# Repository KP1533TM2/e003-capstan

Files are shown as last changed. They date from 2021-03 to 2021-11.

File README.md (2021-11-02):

# e003-capstan
Проект блока управления ведущими двигателями ДМ-1, ДМ-5 (применяемые в магнитофонах Олимп, Электроника ТА1-003) с кварцевой стабилизацией.

Основан на коде [контроллера ведущего двигателя самодельной кассетной деки TK-140 leoniv](http://leoniv.diod.club/projects/audio/tk-140/tk-140.html).

ZCD для сетевого напряжения взят и адаптирован [отсюда](https://cdn.hackaday.io/files/1597066832861504/SimpleIsolatedZeroCrossDetector.pdf).

# Отличия от БУВД Олимп 005
- Иной форм-фактор платы (расчитано на доработанный Олимп 003);
- Силовой каскад реализован простым преобразователем напряжения в ток;
- ФАПЧ, формирование синусоидального тока выполнены на микроконтроллере;
- Реализовано торможение при смене скорости кратковременным реверсом;

# Схема
Актуальная версия схемы (для rev1) лежит [тут](/hw/rev1/main.pdf).

# TODO:
- [x] "чистовая" плата - предположительно rev1;
- [ ] АПЧ сетевого напряжения;
- [ ] переключение реле синхронно переходу через 0 для сбережения контактов (?);
- [ ] описание.

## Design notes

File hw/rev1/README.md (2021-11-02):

# Краткое описание rev1

Ревизия 1 - первая "чистовая" печатная плата.

[Схема этой платы](./main.pdf).

Основные моменты:
* Сложная оригинальная схема петлевого фильтра, модулятора тока и силового
каскада полностью заменена на фильтр ШИМ с преобразователем V→I с применением
полевого транзистора.
* Модуляция синусом реализована таблично и воздействует на выход PID-регулятора.
* Интервал полупериода сетевого напряжения снимается посредством схемы ZCD с
обмотки трансформатора, питающей ведущий двигатель.
* Номиналы схемы ZCD эмпирически подобраны так, чтобы при трехступенчатой форме
сетевого напряжения (с ИБП) схема стабильно формировала лог.0 при "ступеньке"
0В;
* Добавлены крепежные отверстия по периметру.

# Картинки

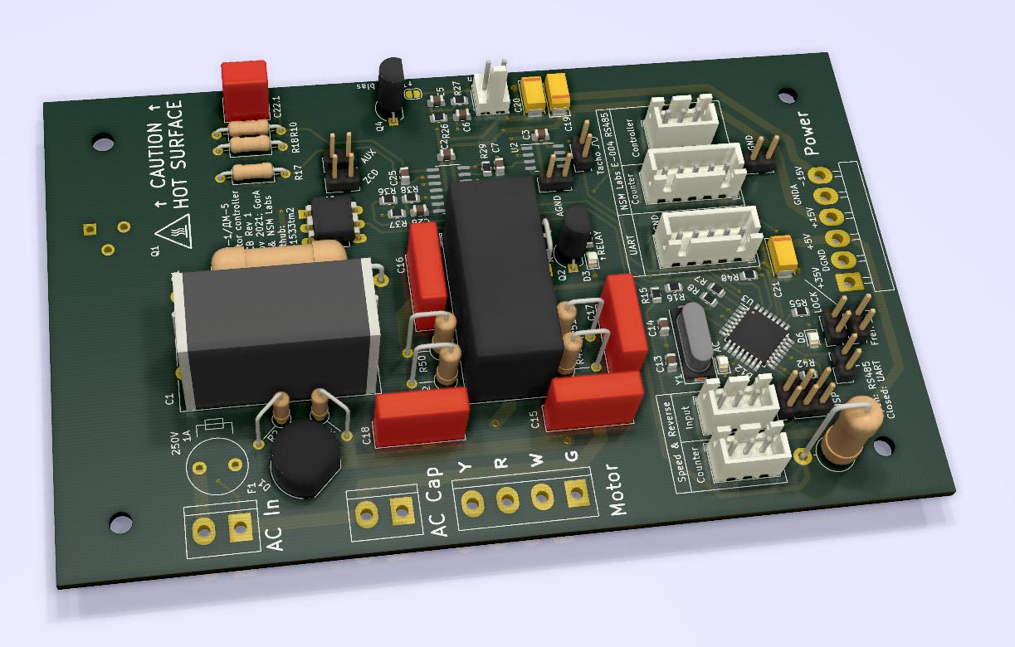
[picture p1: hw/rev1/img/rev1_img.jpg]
rev 1 pcb rev1


To be continued...

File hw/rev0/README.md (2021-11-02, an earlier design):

# Краткое описание rev0

Ревизия 0 - опытная печатная плата, на которой разведена схема аналогового
перемножителя на м/сх К504НТ3, обеспечивающего формирование синусоидального тока
двигателя.

[Схема этой платы](./main.pdf).

Схема ФАПЧ была заменена микроконтроллером.

Эта схема имеет ряд недостатков, основными из которых являются:
* Сложность в наладке;
* Трудонодоступность К504НТ3 и прочих полевых сборок;
* Схема обеспечивает модуляцию только при работе от переменного тока
синусоидальной формы.

# Картинки (макет rev1, rev0)

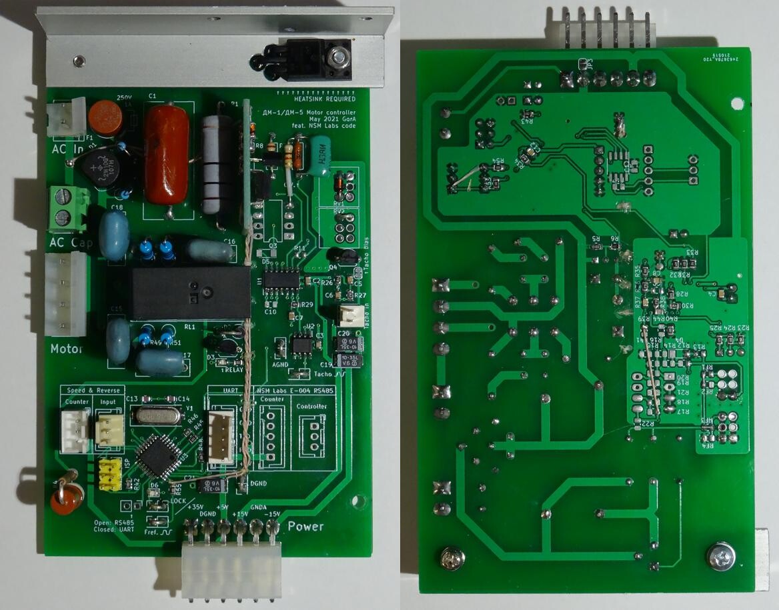
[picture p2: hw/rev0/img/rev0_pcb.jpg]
rev 0 top and bottom Макет rev1, собранный на плате rev0


Так выглядит плата rev0, с доработками, которые вошли в rev1.

Перпендикулярно распаянная макетная плата вблизи металлического уголка -
детектор перехода сетевого напряжения через 0 (Zero Crossing Detector),
необходимый для подстройки синтезируемого выпрямленного синуса к периоду
сетевого напряжения.

Вместо аналогового перемножителя распаян преобразователь напряжения в ток,
через который посредством фильтрованного PWM "напрямую", линейно управляет
микроконтроллер. Это позволяет осуществить модуляцию выхода PID-регулятора
модулем синуса программно, и тем самым избавиться от труднодоступной
транзисторной сборки К504НТ3 и её обвязки, нуждающейся в регулировке.

Дополнительный положительный побочный эффект такого решения заключается в
возможности работы этой схемы с переменным током формы, отличной от
синусоидальной (например, с трехступенчатой формой от ИБП).

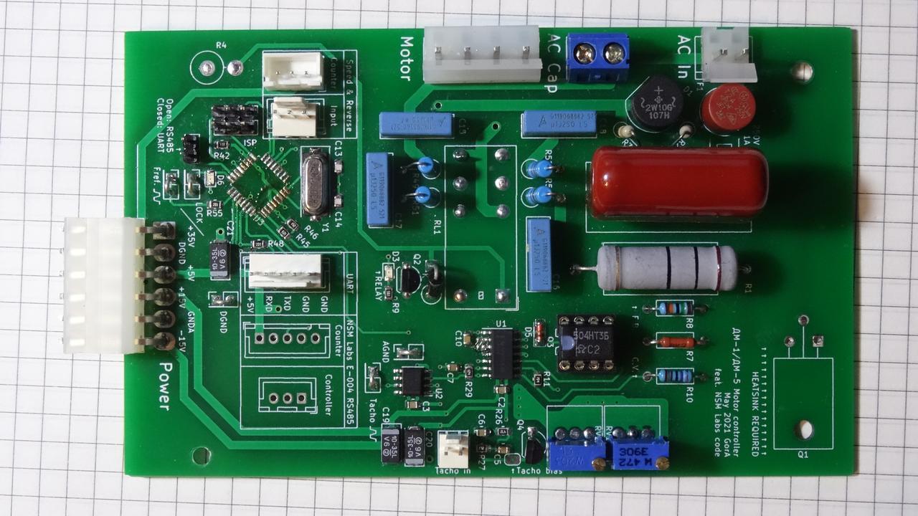
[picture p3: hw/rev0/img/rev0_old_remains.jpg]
rev 0 old Останки чистой, аналоговой rev0


Останки ревизии 0, собранные с аналоговым перемножителем-модулятором, для
истории.

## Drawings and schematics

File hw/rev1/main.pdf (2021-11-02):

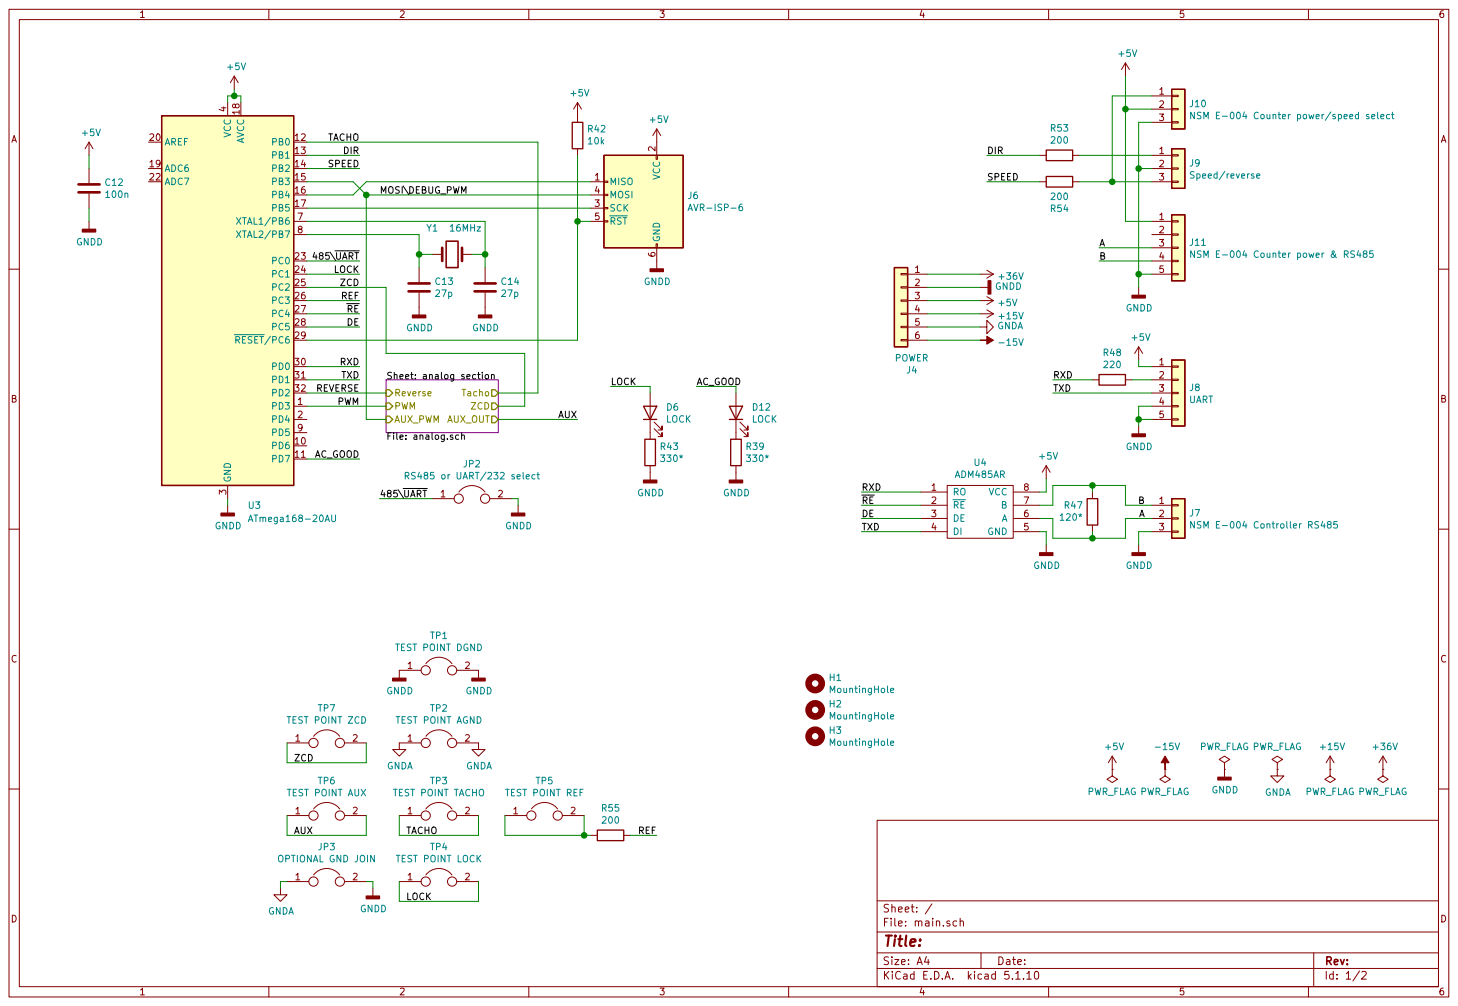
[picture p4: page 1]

2 SCK 3 MOSI 4 RST 5 GND

Sheet: analog section
File: analog.sch Tacho PWM

Id: 1/2 Title: File: main.sch Sheet: /

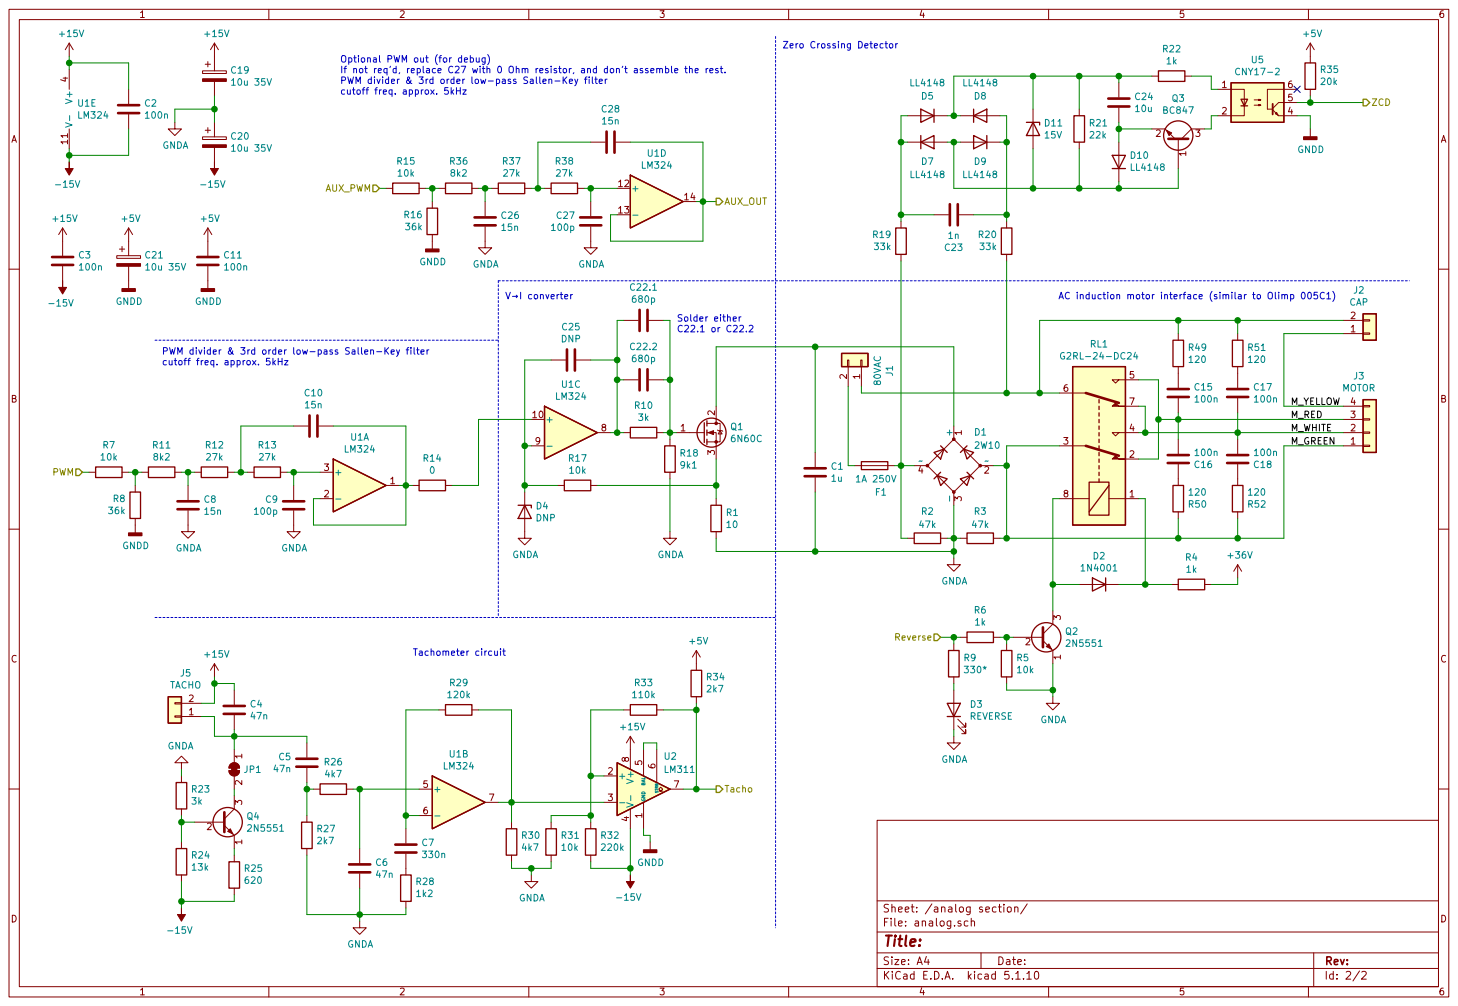
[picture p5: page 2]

Optional PWM out (for debug)
If not req'd, replace C27 with 0 Ohm resistor, and don't assemble the rest.
PWM divider & 3rd order low-pass Sallen-Key filter

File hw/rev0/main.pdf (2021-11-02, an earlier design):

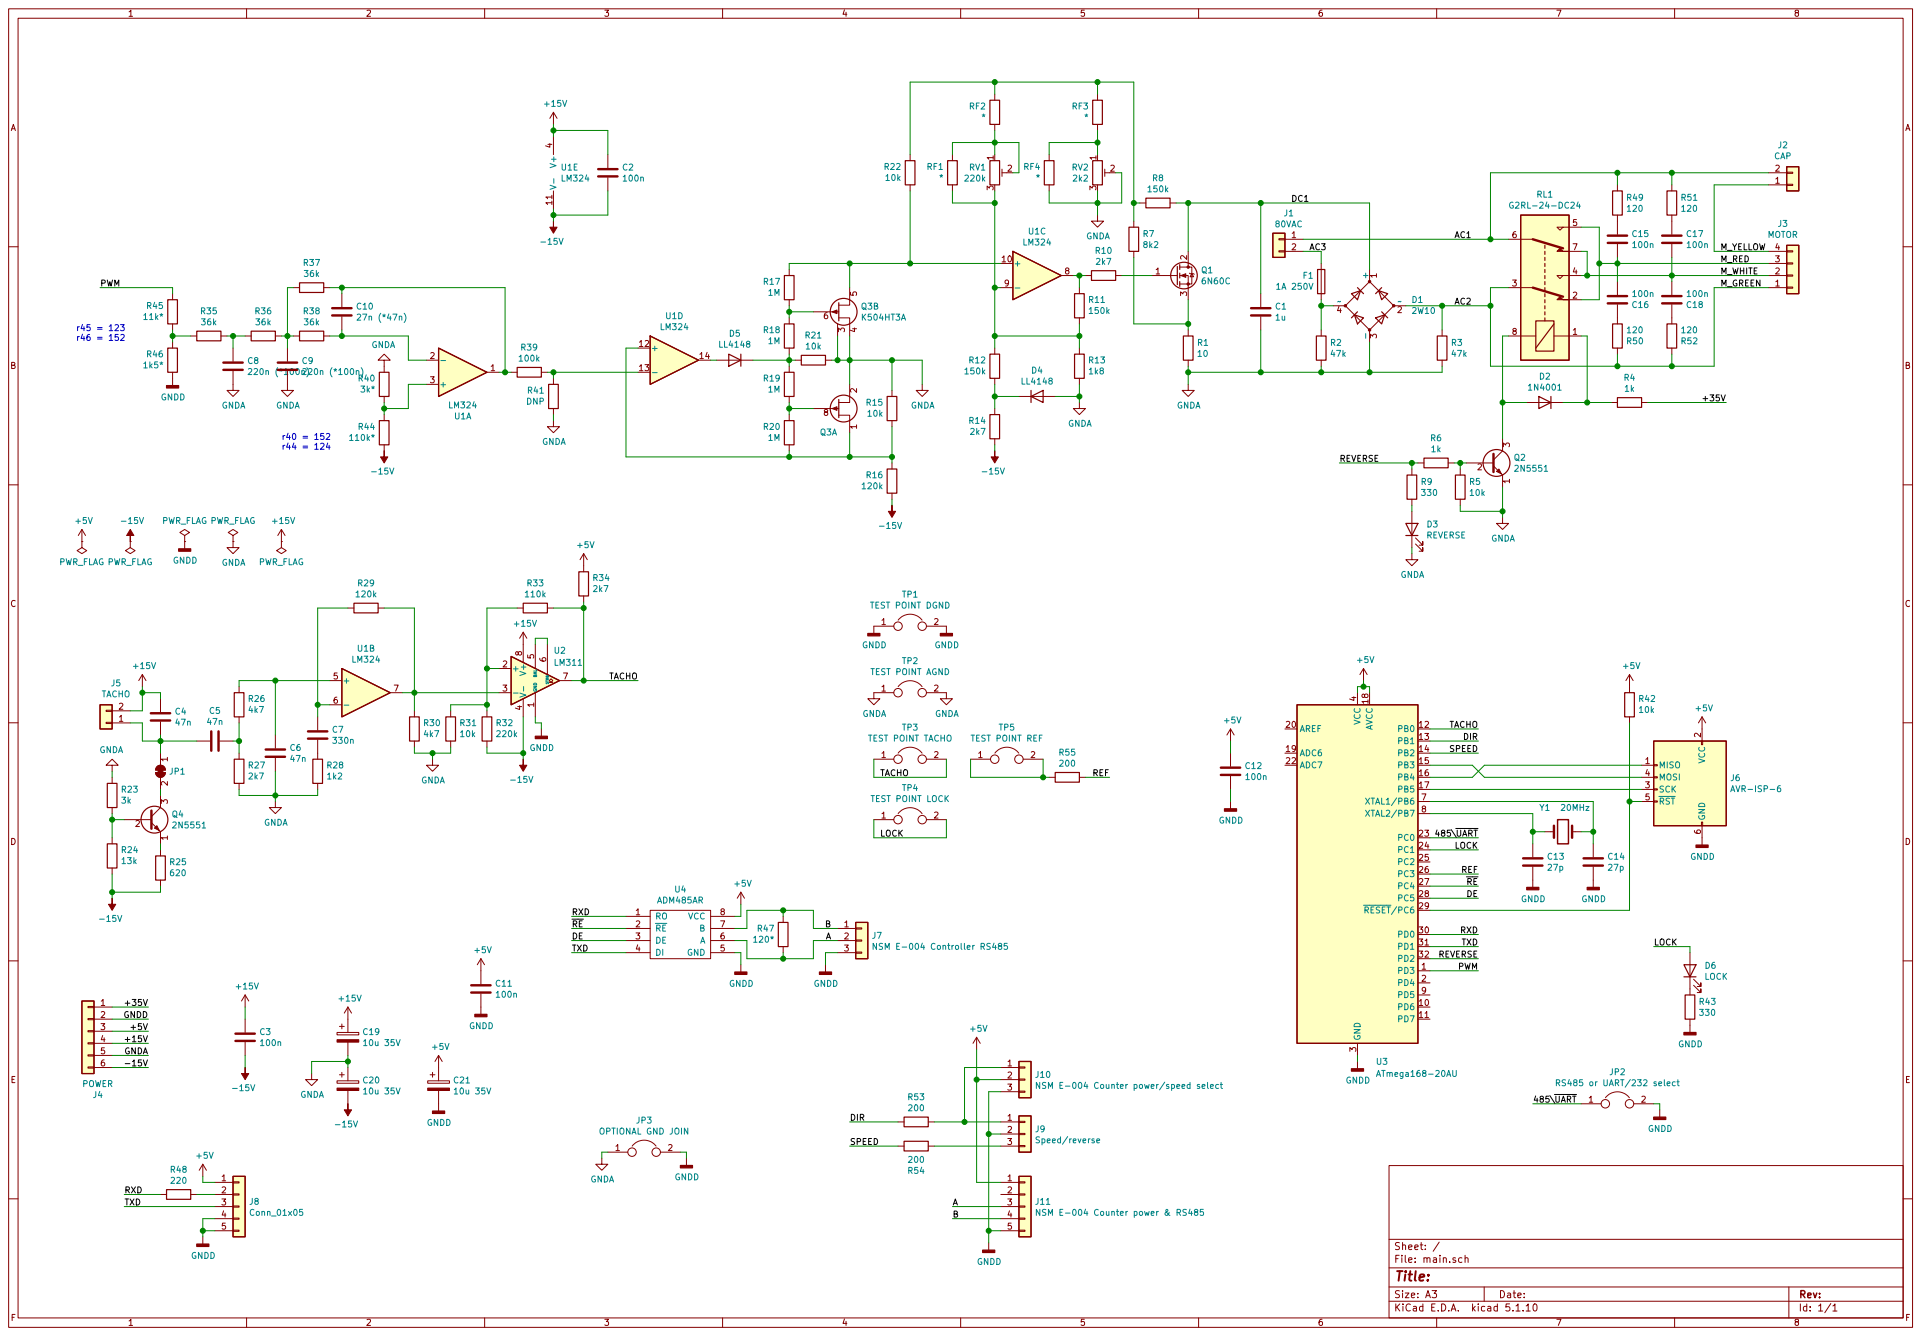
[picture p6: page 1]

J1 80VAC

Id: 1/1 Title: File: main.sch Sheet: /

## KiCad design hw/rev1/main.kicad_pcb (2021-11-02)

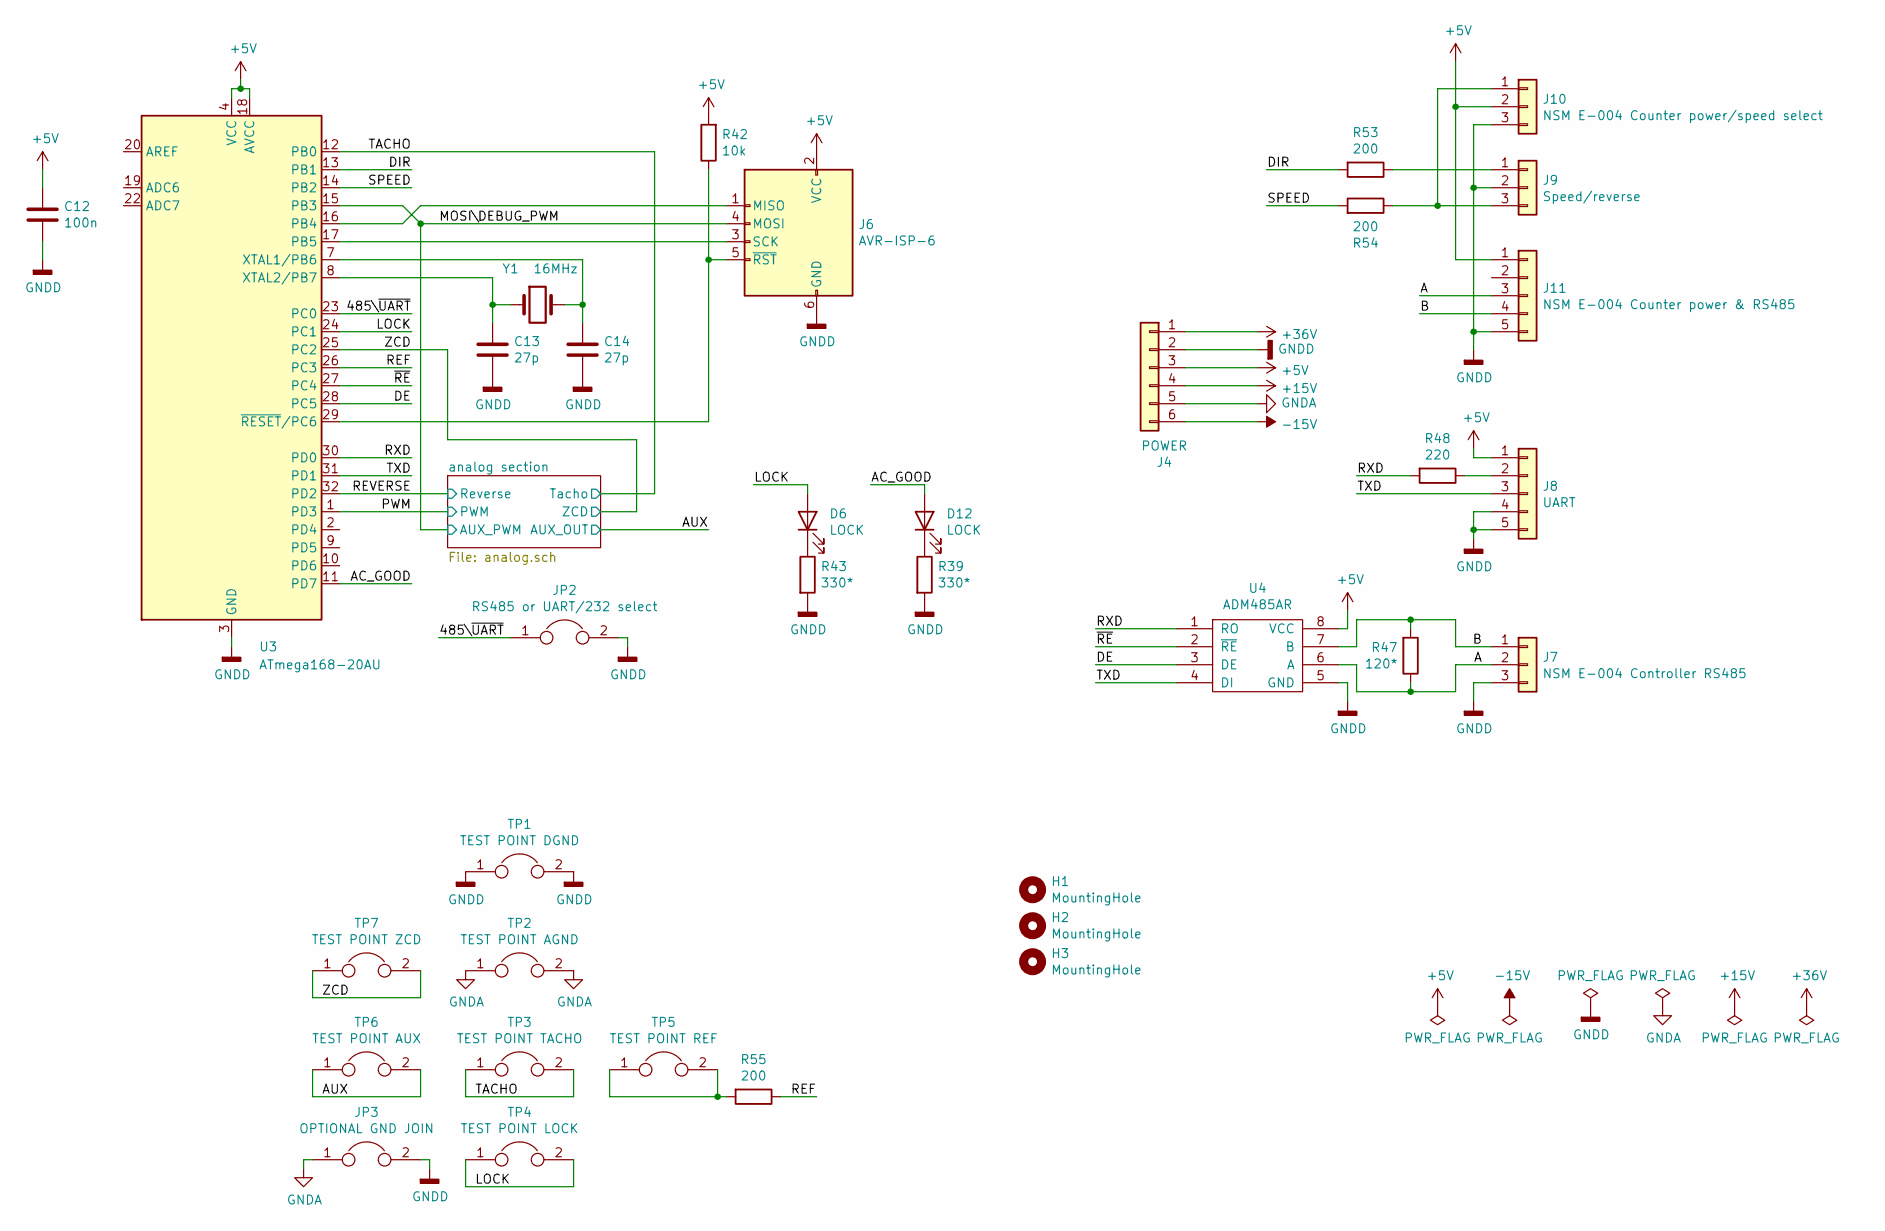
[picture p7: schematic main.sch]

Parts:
C12: 100n; C_0805_2012Metric
C13, C14: 27p; C_0805_2012Metric
D6, D12: LOCK; LED_0805_2012Metric
H1, H2, H3: MountingHole; MountingHole_3.2mm_M3
J4: POWER; Molex_KK-396_Right_Angle
J6: AVR-ISP-6; PinHeader_2x03_P2.54mm_Vertical
J7: NSM E-004 Controller RS485; JST_XH_B3B-XH-A_1x03_P2.50mm_Vertical
J8: UART; JST_XH_B5B-XH-A_1x05_P2.50mm_Vertical
J9: Speed/reverse; JST_XH_B3B-XH-A_1x03_P2.50mm_Vertical
J10: NSM E-004 Counter power/speed select; JST_XH_B3B-XH-A_1x03_P2.50mm_Vertical
J11: NSM E-004 Counter power & RS485; JST_XH_B5B-XH-A_1x05_P2.50mm_Vertical
JP2: RS485 or UART/232 select; PinHeader_1x02_P2.54mm_Vertical
JP3: OPTIONAL GND JOIN; SolderJumper-2_P1.3mm_Open_RoundedPad1.0x1.5mm
R39, R43: 330*; R_0805_2012Metric
R42: 10k; R_0805_2012Metric
R47: 120*; R_0805_2012Metric
R48: 220; R_0805_2012Metric
R53, R54, R55: 200; R_0805_2012Metric
TP1: TEST POINT DGND; PinHeader_2x01_P2.54mm_Vertical
TP2: TEST POINT AGND; PinHeader_2x01_P2.54mm_Vertical
TP3: TEST POINT TACHO; PinHeader_2x01_P2.54mm_Vertical
TP4: TEST POINT LOCK; PinHeader_2x01_P2.54mm_Vertical
TP5: TEST POINT REF; PinHeader_2x01_P2.54mm_Vertical
TP6: TEST POINT AUX; PinHeader_2x01_P2.54mm_Vertical
TP7: TEST POINT ZCD; PinHeader_2x01_P2.54mm_Vertical
U3: ATmega168-20AU; TQFP-32_7x7mm_P0.8mm
U4: ADM485AR; SO-8_3.9x4.9mm_P1.27mm
Y1: 16MHz; Crystal_SMD_HC49-SD

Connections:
+5V: C12.1, J4.3, J6.2 (VCC), J8.1, J10.2, J11.1, R42.2, U3.4 (VCC), U3.6 (VCC), U3.18 (AVCC), U4.8 (VCC); also elsewhere on the board
+15V: J4.4; also elsewhere on the board
+36V: J4.1; also elsewhere on the board
-15V: J4.6; also elsewhere on the board
/485\~UART: JP2.1, U3.23 (PC0)
/A: J7.2, J11.3, R47.1, U4.6 (A)
/AC_GOOD: D12.2 (A), U3.11 (PD7)
/AUX: TP6.1, TP6.2; also elsewhere on the board
/B: J7.1, J11.4, R47.2, U4.7 (B)
/DE: U3.28 (PC5), U4.3 (DE)
/DIR: R53.2, U3.13 (PB1)
/LOCK: D6.2 (A), TP4.1, TP4.2, U3.24 (PC1)
/MOSI\DEBUG_PWM: J6.4 (MOSI), U3.15 (PB3); also elsewhere on the board
/PWM: U3.1 (PD3); also elsewhere on the board
/REF: R55.1, U3.26 (PC3)
/REVERSE: U3.32 (PD2); also elsewhere on the board
/RXD: R48.2, U3.30 (PD0), U4.1 (RO)
/SPEED: R54.2, U3.14 (PB2)
/TACHO: TP3.1, TP3.2, U3.12 (PB0); also elsewhere on the board
/TXD: J8.3, U3.31 (PD1), U4.4 (DI)
/ZCD: TP7.1, TP7.2, U3.25 (PC2); also elsewhere on the board
/~RE: U3.27 (PC4), U4.2 (~RE)
GNDA: J4.5, JP3.1, TP2.1, TP2.2; also elsewhere on the board
GNDD: C12.2, C13.2, C14.2, J4.2, J6.6 (GND), J7.3, J8.4, J8.5, J9.2, J10.3, J11.5, JP2.2, JP3.2, R39.2, R43.2, TP1.1, TP1.2, U3.3 (GND), U3.5 (GND), U3.21 (GND), U4.5 (GND); also elsewhere on the board
unnamed: C13.1, U3.8 (XTAL2/PB7), Y1.1
unnamed: C14.1, U3.7 (XTAL1/PB6), Y1.2
unnamed: D6.1 (K), R43.1
unnamed: D12.1 (K), R39.1
unnamed: J6.1 (MISO), U3.16 (PB4)
unnamed: J6.3 (SCK), U3.17 (PB5)
unnamed: J6.5 (~RST), R42.1, U3.29 (~RESET~/PC6)
unnamed: J8.2, R48.1
unnamed: J9.1, R53.1
unnamed: J9.3, J10.1, R54.1
unnamed: R55.2, TP5.1, TP5.2

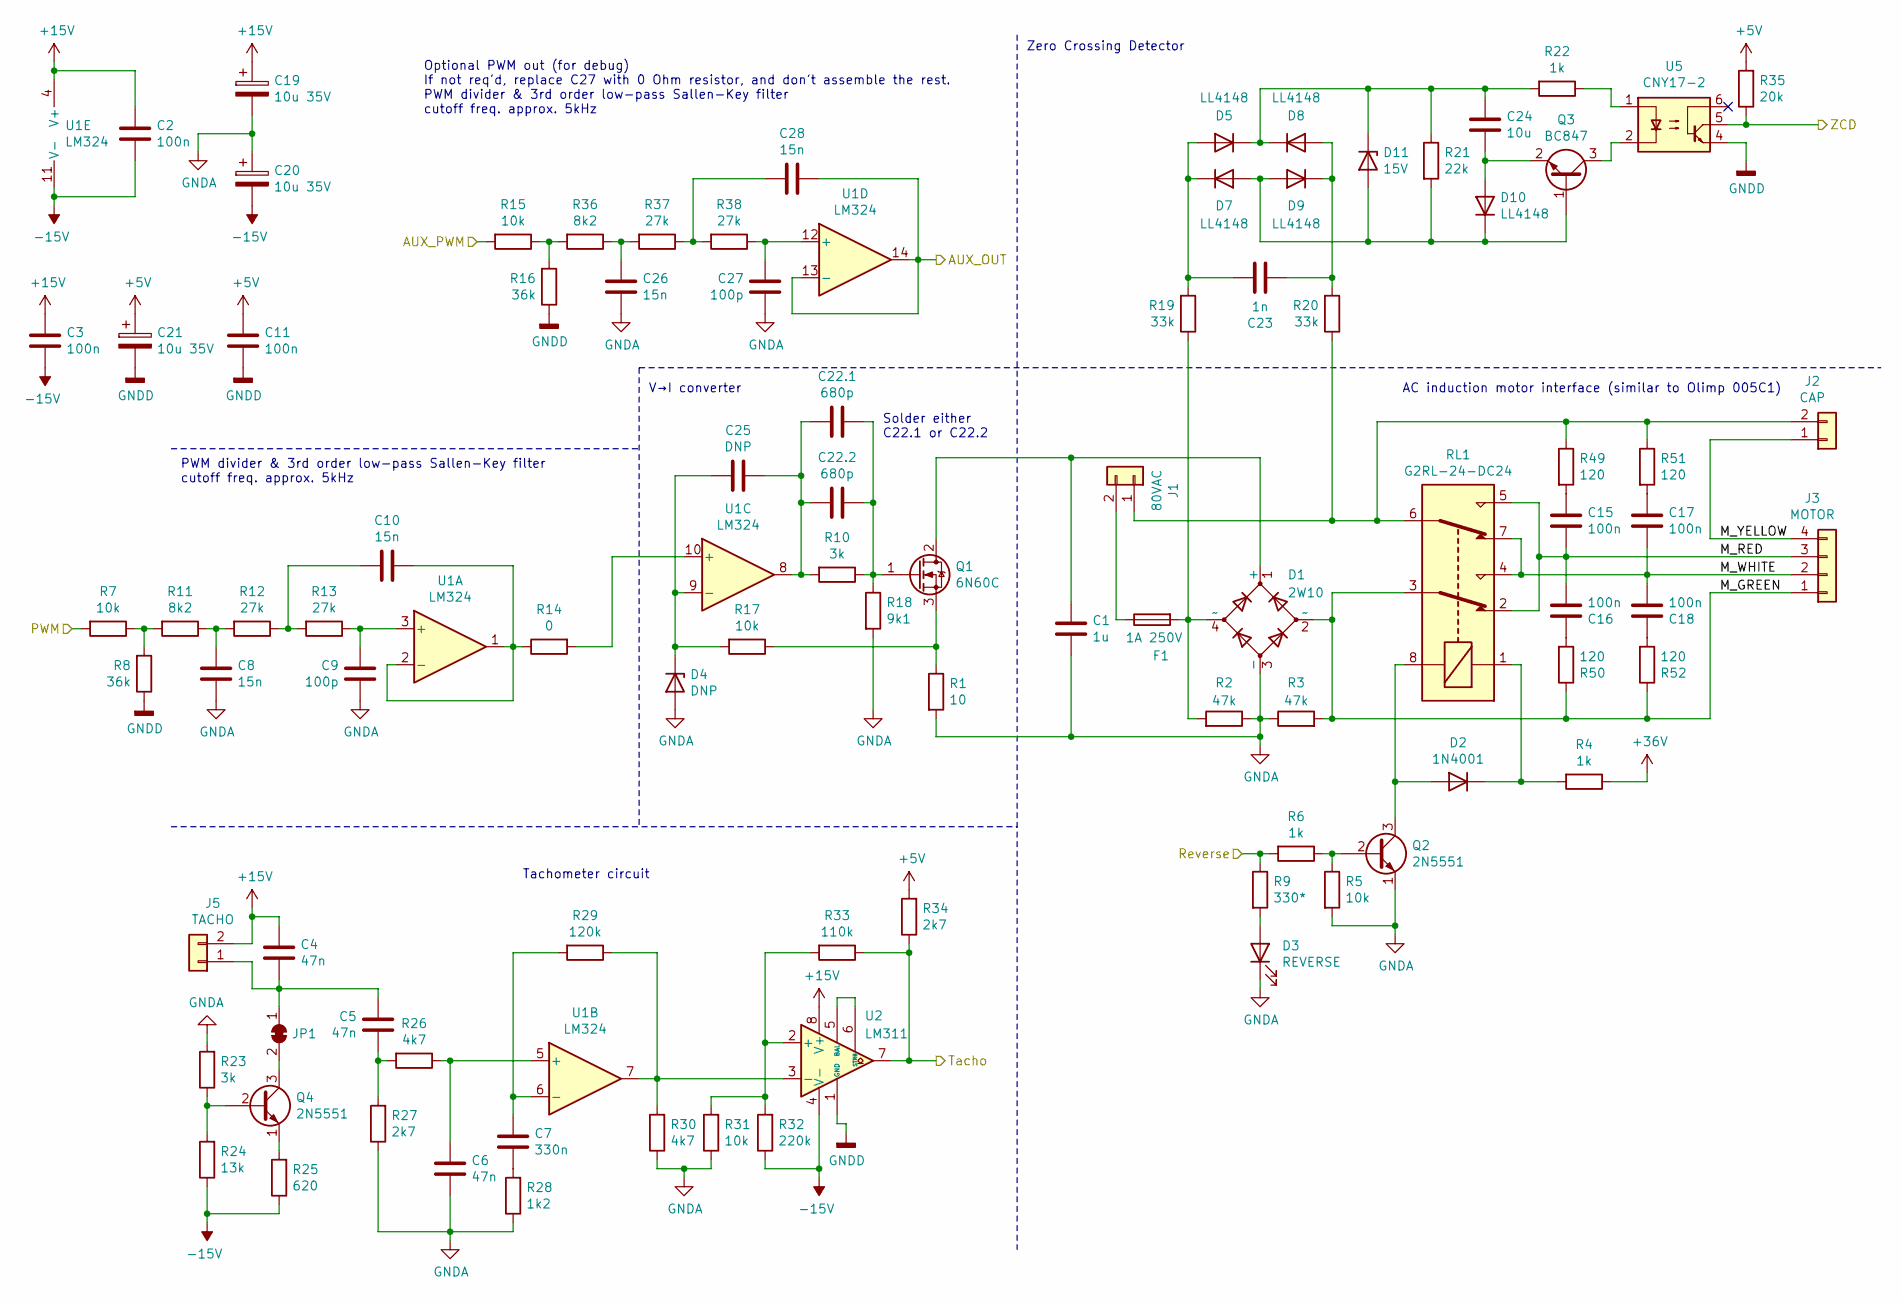
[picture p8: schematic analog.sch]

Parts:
C1: 1u; C_Rect_L29.0mm_W12.2mm_P27.50mm_MKT
C2, C3, C11: 100n; C_0805_2012Metric
C4, C5, C6: 47n; C_0805_2012Metric
C7: 330n; C_0805_2012Metric
C8, C10, C26, C28: 15n; C_0805_2012Metric
C9, C27: 100p; C_0805_2012Metric
C15, C16, C17, C18: 100n; C_Rect_L13.0mm_W4.0mm_P10.00mm_FKS3_FKP3_MKS4
C19, C20, C21: 10u 35V; CP_EIA-6032-28_Kemet-C
C22.1: 680p; C_Rect_L7.0mm_W4.5mm_P5.00mm
C22.2: 680p; C_0805_2012Metric
C23: 1n; C_1206_3216Metric
C24: 10u; C_1206_3216Metric
C25: DNP; C_0805_2012Metric
D1: 2W10; Diode_Bridge_Round_D9.8mm
D2: 1N4001; D_DO-41_SOD81_P5.08mm_Vertical_KathodeUp
D3: REVERSE; LED_0805_2012Metric
D4: DNP; D_SOD-123
D5, D7, D8, D9, D10: LL4148; D_MiniMELF
D11: 15V; D_SOD-123
F1: 1A 250V; Fuse_Littelfuse_372_D8.50mm
J1: 80VAC; TerminalBlock_bornier-2_P5.08mm
J2: CAP; TerminalBlock_bornier-2_P5.08mm
J3: MOTOR; TerminalBlock_bornier-4_P5.08mm
J5: TACHO; Molex_KK-254_AE-6410-02A_1x02_P2.54mm_Vertical
JP1: SolderJumper_2_Bridged; SolderJumper-2_P1.3mm_Bridged_RoundedPad1.0x1.5mm
Q1: 6N60C; TO-220F-3_Horizontal_TabDown_no_silk
Q2, Q4: 2N5551; TO-92L_Inline_Wide
Q3: BC847; SOT-23
R1: 10; R_Axial_DIN0922_L20.0mm_D9.0mm_P30.48mm_Horizontal
R2, R3: 47k; R_Axial_DIN0207_L6.3mm_D2.5mm_P5.08mm_Vertical
R4: 1k; R_Axial_DIN0614_L14.3mm_D5.7mm_P5.08mm_Vertical
R5, R7, R15, R31: 10k; R_0805_2012Metric
R6: 1k; R_0805_2012Metric
R8, R16: 36k; R_0805_2012Metric
R9: 330*; R_0805_2012Metric
R10: 3k; R_Axial_DIN0207_L6.3mm_D2.5mm_P10.16mm_Horizontal
R11, R36: 8k2; R_0805_2012Metric
R12, R13, R37, R38: 27k; R_0805_2012Metric
R14: 0; R_0805_2012Metric
R17: 10k; R_Axial_DIN0207_L6.3mm_D2.5mm_P10.16mm_Horizontal
R18: 9k1; R_Axial_DIN0207_L6.3mm_D2.5mm_P10.16mm_Horizontal
R19, R20: 33k; R_1206_3216Metric
R21: 22k; R_1206_3216Metric
R22: 1k; R_1206_3216Metric
R23: 3k; R_0805_2012Metric
R24: 13k; R_0805_2012Metric
R25: 620; R_0805_2012Metric
R26, R30: 4k7; R_0805_2012Metric
R27, R34: 2k7; R_0805_2012Metric
R28: 1k2; R_0805_2012Metric
R29: 120k; R_0805_2012Metric
R32: 220k; R_0805_2012Metric
R33: 110k; R_0805_2012Metric
R35: 20k; R_0805_2012Metric
R49, R50, R51, R52: 120; R_Axial_DIN0309_L9.0mm_D3.2mm_P5.08mm_Vertical
RL1: G2RL-24-DC24; Relay_DPDT_Omron_G2RL
U1: LM324; SO-14_3.9x8.65mm_P1.27mm
U2: LM311; SO-8_3.9x4.9mm_P1.27mm
U5: CNY17-2; DIP-6_W7.62mm_LongPads

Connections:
+5V: C11.1, C21.1, R34.2, R35.2; also elsewhere on the board
+15V: C2.1, C3.1, C4.1, C19.1, J5.2, U1.4 (V+), U2.8 (V+); also elsewhere on the board
+36V: R4.1; also elsewhere on the board
-15V: C2.2, C3.2, C20.2, R24.1, R25.1, R32.1, U1.11 (V-), U2.4 (V-); also elsewhere on the board
/AUX: C28.1, U1.13 (-), U1.14; also elsewhere on the board
/MOSI\DEBUG_PWM: R15.2; also elsewhere on the board
/PWM: R7.2; also elsewhere on the board
/REVERSE: R6.2, R9.1; also elsewhere on the board
/TACHO: R33.1, R34.1, U2.7; also elsewhere on the board
/ZCD: R35.1, U5.5; also elsewhere on the board
/analog section/M_GREEN: D1.2 (~~), J3.1, R3.2, R50.1, R52.1, RL1.3
/analog section/M_RED: C15.2, C16.2, J3.3, RL1.2, RL1.5
/analog section/M_WHITE: C17.2, C18.2, J3.2, RL1.4, RL1.7
/analog section/M_YELLOW: J2.1, J3.4
GNDA: C1.2, C6.2, C8.2, C9.2, C19.2, C20.1, C26.2, C27.2, D1.3 (-), D3.1 (K), D4.2 (A), Q2.1 (E), R1.2, R2.1, R3.1, R5.2, R18.2, R23.2, R27.1, R28.1, R30.1, R31.1; also elsewhere on the board
GNDD: C11.2, C21.2, R8.1, R16.1, U2.1 (GND), U5.4; also elsewhere on the board
unnamed: C1.1, D1.1 (+), Q1.2 (D)
unnamed: C4.2, C5.1, J5.1, JP1.1 (A)
unnamed: C5.2, R26.2, R27.2
unnamed: C6.1, R26.1, U1.5 (+)
unnamed: C7.1, R29.2, U1.6 (-)
unnamed: C7.2, R28.2
unnamed: C8.1, R11.1, R12.2
unnamed: C9.1, R13.1, U1.3 (+)
unnamed: C10.1, R14.1, U1.1, U1.2 (-)
unnamed: C10.2, R12.1, R13.2
unnamed: C15.1, R49.2
unnamed: C16.1, R50.2
unnamed: C17.1, R51.2
unnamed: C18.1, R52.2
unnamed: C22.1.1, C22.2.1, Q1.1 (G), R10.1, R18.1
unnamed: C22.1.2, C22.2.2, C25.1, R10.2, U1.8
unnamed: C23.1, D5.2 (A), D7.1 (K), R19.2
unnamed: C23.2, D8.2 (A), D9.1 (K), R20.2
unnamed: C24.1, D5.1 (K), D8.1 (K), D11.1 (K), R21.1, R22.2
unnamed: C24.2, D10.2 (A), Q3.2 (E)
unnamed: C25.2, D4.1 (K), R17.2, U1.9 (-)
unnamed: C26.1, R36.1, R37.2
unnamed: C27.1, R38.1, U1.12 (+)
unnamed: C28.2, R37.1, R38.2
unnamed: D1.4 (~~), F1.2, R2.2, R19.1
unnamed: D2.1 (K), R4.2, RL1.1
unnamed: D2.2 (A), Q2.3 (C), RL1.8
unnamed: D3.2 (A), R9.2
unnamed: D7.2 (A), D9.2 (A), D10.1 (K), D11.2 (A), Q3.1 (B), R21.2
unnamed: F1.1, J1.2
unnamed: J1.1, J2.2, R20.1, R49.1, R51.1, RL1.6
unnamed: JP1.2 (B), Q4.3 (C)
unnamed: Q1.3 (S), R1.1, R17.1
unnamed: Q2.2 (B), R5.1, R6.1
unnamed: Q3.3 (C), U5.2
unnamed: Q4.1 (E), R25.2
unnamed: Q4.2 (B), R23.1, R24.2
unnamed: R7.1, R8.2, R11.2
unnamed: R14.2, U1.10 (+)
unnamed: R15.1, R16.2, R36.2
unnamed: R22.1, U5.1
unnamed: R29.1, R30.2, U1.7, U2.3 (-)
unnamed: R31.2, R32.2, R33.2, U2.2 (+)
unnamed: U2.5 (BAL), U2.6 (STRB)

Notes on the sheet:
PWM divider & 3rd order low-pass Sallen-Key filter cutoff freq. approx. 5kHz
V→I converter
Tachometer circuit
AC induction motor interface (similar to Olimp 005C1)
Zero Crossing Detector
Optional PWM out (for debug) If not req'd, replace C27 with 0 Ohm resistor, and don't assemble the rest. PWM divider & 3rd order low-pass Sallen-Key filter cutoff freq. approx. 5kHz
Solder either C22.1 or C22.2

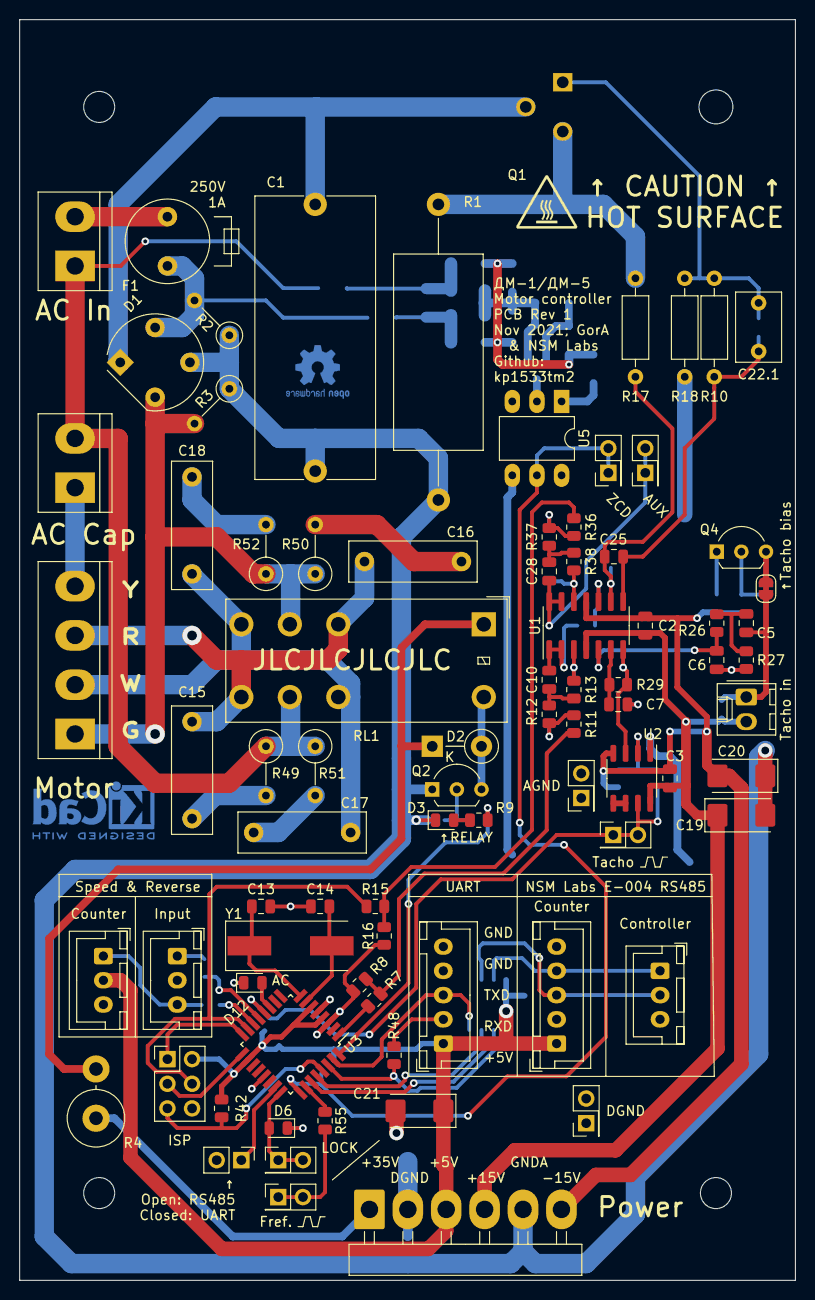
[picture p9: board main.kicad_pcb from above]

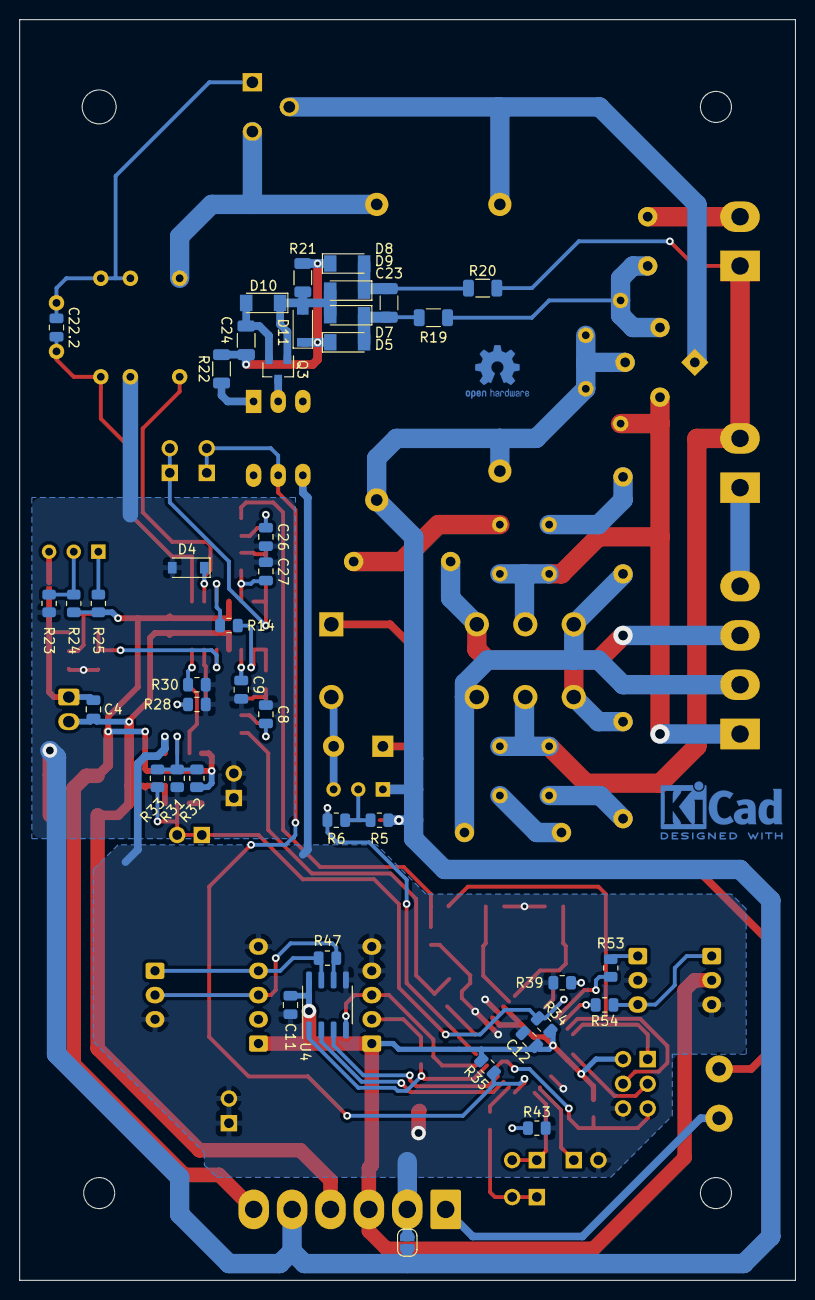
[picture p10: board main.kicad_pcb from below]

Board: 2 copper layers, 80.0 x 130.0 mm, 127 parts (42 on the bottom side), 83 nets.

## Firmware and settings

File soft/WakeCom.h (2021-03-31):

#ifndef WakeComH
#define WakeComH

#include <SysUtils.hpp>
#include <SyncObjs.hpp>
#include <Classes.hpp>

#define DEFAULT_BAUD_RATE  19200 //значение скорости по умолчанию, бод
#define DEFAULT_TX_TIMEOUT    50 //timeout на передачу по умолчанию, мс
#define DEFAULT_RX_TIMEOUT    50 //timeout на прием по умолчанию, мс
#define LONG_RX_TIMEOUT      400 //длинный timeout на прием, мс

#define DEFAULT_RTS_STATE  RTS_CONTROL_TOGGLE  //состояние RTS по умолчанию
#define DEFAULT_DTR_STATE  DTR_CONTROL_DISABLE //состояние DTR по умолчанию

#define FRAME     250   //размер буфера Wake

//Коды ошибок:
enum WakeErr_t
{
  ERR_NO, //no error
  ERR_TX, //Rx/Tx error
  ERR_BU, //device busy error
  ERR_RE, //device not ready error
  ERR_PA, //parameters value error
  ERR_NR, //no replay
  ERR_NC  //no carrier
};

//Коды стандартных команд:
enum WakeCmd_t
{
  CMD_NOP,     //нет операции
  CMD_ERR,     //ошибка приема пакета
  CMD_ECHO,    //эхо
  CMD_INFO,    //чтение информации об устройстве
  CMD_SETADDR, //установка адреса
  CMD_GETADDR  //чтение адреса
};

#define LO(x)    (x & 0xFF)
#define HI(x)    ((x >> 8) & 0xFF)
#define BYTE1(x) LO(x)
#define BYTE2(x) HI(x)
#define BYTE3(x) ((x >> 16) & 0xFF)
#define BYTE4(x) ((x >> 24) & 0xFF)
#define WORD(h, l) ((h << 8) | l)
#define DWORD(b3,b2,b1,b0) ((WORD(b3,b2) << 16) | WORD(b1,b0))

#define _ENTER_COMMAND(x) x->Enter();try{
#define _LEAVE_COMMAND(x) }__finally{x->Leave();}

//------------------ Класс реализации протокола WAKE: -----------------------

class TWakeCom : public TObject
{
private:
  HANDLE hCom;         //handle порта
  DCB dcb;             //структора DCB
  DCB dcbc;            //сохраненная структура DCB
  COMMTIMEOUTS ComTo;  //структура timeout-ов
  COMMTIMEOUTS ComToc; //сохраненная структура timeout-ов
  AnsiString FName;    //логическое имя порта
  int FNumber;         //номер порта
  int FBaudRate;       //скорость обмена
  bool Platform_NT;    //флаг типа платформы
  WORD BaseAddress;    //базовый адрес UART (not for NT systems)
  bool RtsToggle;      //флаг режима RTS toggle (not for NT systems)

  void __fastcall SetNumber(int number);     //установка номера порта
  void __fastcall SetName(AnsiString name);  //установка имени порта

  enum WStuff_t
  {
    FEND  = 0xC0,        //Frame END
    FESC  = 0xDB,        //Frame ESCape
    TFEND = 0xDC,        //Transposed Frame END
    TFESC = 0xDD         //Transposed Frame ESCape
  };
  enum WCrc_t
  {
    CRC_INIT = 0xDE      //начальное значение контрольной суммы
  };
  int FTxAddr;           //передаваемый адрес
  int FTxCmd;            //код передаваемой команды
  int FTxPtr;            //указатель буфера передачи
  int FRxPtr;            //указатель буфера приема
  unsigned char RxN;     //количество принятых байт
  AnsiString FTxCmdName; //имя передаваемой команды
  AnsiString FDeviceName; //имя устройства
  void __fastcall RxByte(unsigned char &b); //прием байта
  BYTE __fastcall PortIn(WORD Address); //чтение порта (not for NT systems)
  void __fastcall ByteStuff(unsigned char b, DWORD &bptr, unsigned char *buff);
  void __fastcall ByteDeStuff(unsigned char &b);
  void __fastcall DowCRC(unsigned char b, unsigned char &crc); //вычисление CRC
  void __fastcall RxFrame(unsigned char &Addr,
                          unsigned char &Cmd,
                          unsigned char &Nbt,
                          unsigned char *Data); //прием пакета
  void __fastcall TxFrame(unsigned char Addr,
                          unsigned char Cmd,
                          unsigned char Nbt,
                          unsigned char *Data); //передача пакета
  unsigned char FTxData[FRAME]; //буфер передачи
  unsigned char FRxData[FRAME]; //буфер приема

protected:
  TCriticalSection *CmdCrSec; //критическая секция для выполнения команд
  void __fastcall NewCmd(int cmd, AnsiString name); //начало формирования пакета
  void __fastcall AddByte(unsigned char b);  //добавление байта в буфер
  void __fastcall AddWord(unsigned short b); //добавление слова в буфер
  void __fastcall AddDWord(unsigned int b);  //добавление двойного слова в буфер
  void __fastcall AddData(char *d, int count); //добавление данных в буфер
  void __fastcall SendCmd(int a = 0); //передача пакета по заданному адресу
  unsigned char __fastcall  GetByte(void);   //чтение байта из буфера
  unsigned short __fastcall  GetWord(void);  //чтение слова из буфера
  unsigned int __fastcall  GetDWord(void);   //чтение двойного слова из буфера
  void __fastcall GetData(char *d, int count); //чтение данных из буфера
  int __fastcall GetRxN(void); //чтение количества принятых байт

public:
  __fastcall TWakeCom();  //конструктор
  __fastcall ~TWakeCom(); //деструктор

  int __fastcall NameToNumber(AnsiString name); //преобразование имени в номер
  AnsiString __fastcall NumberToName(int number); //преобразование номера в имя
  void __fastcall GetPortList(TStringList *APortBox); //получение списка портов
  bool __fastcall Access(int PortNumber); //проверка доступности порта по номеру
  bool __fastcall Access(AnsiString PortName); //проверка доступности порта по имени
  void __fastcall Open(int PortNumber); //открыть порт по номеру
  void __fastcall Open(AnsiString PortName); //открыть порт по имени
  void __fastcall GetDeviceList(TStringList *ADeviceBox); //создать список устр.
  void __fastcall GetNetDeviceList(AnsiString PortName,      //создать список
                                   TStringList *ADeviceBox); //сетевых устр.
  void __fastcall OpenDevice(AnsiString DevName); //открыть порт по имени устр.
  void __fastcall Close(); //закрыть порт
  void __fastcall SetBaudRate(int baudrate); //установка скорости обмена
  void __fastcall SetMode(DWORD RtsMode, DWORD DtrMode); //установка режима
  void __fastcall SetTo(DWORD RxTo, DWORD TxTo); //установка таймаутов
  void __fastcall Purge(void); //очистка буфера порта

  __property int Number = {read=FNumber, write=SetNumber}; //номер порта
  __property AnsiString PortName = {read=FName, write=SetName}; //имя порта
  __property int BaudRate = {read=FBaudRate, write=SetBaudRate}; //скорость
  __property AnsiString DeviceName = {read=FDeviceName}; //имя порта

  AnsiString __fastcall GetInfo(int a = 0); //чтение информации об устройстве
};

//---------------------------------------------------------------------------

#endif

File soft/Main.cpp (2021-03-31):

#include <vcl.h>
#include <fstream> 
#include <iostream.h>
#include <math.h>
#include <dir.h>
#pragma hdrstop

#include "Main.h"
#include "Connect.h"
#include "About.h"
#include "Colours.h"
#include "Settings.h"

#pragma package(smart_init)
#pragma link "FloatEdit"
#pragma link "ThemeMgr"
#pragma link "FloatEdit"
#pragma resource "*.dfm"
TMainForm *MainForm;

//---------------------------------------------------------------------------

__fastcall TMainForm::TMainForm(TComponent* Owner)
        : TForm(Owner)
{
}

//-------------------------- Создание формы: --------------------------------

void __fastcall TMainForm::FormCreate(TObject *Sender)
{ int i;
  //общие параметры:
  Caption = MakeCaption();
  DecimalSeparator = '.';            //десятичный разделитель
  FFileName = "";
  DragAcceptFiles(Handle, 1);        //разрешение drag-n-drop
  //установка DoubleBuffered для компонентов:
  MainForm->DoubleBuffered = 1;
  UnderLogPanel->DoubleBuffered = 1;
  LogPanel->DoubleBuffered = 1;
  CtrlPanel->DoubleBuffered = 1;
  TrsPanel->DoubleBuffered = 1;
  ToolBar->DoubleBuffered = 1;
  TlPanel->DoubleBuffered = 1;
  StatusBar->DoubleBuffered = 1;
  //настройка связи с устройством:
  WakePort = new TWakePort();
  acDisconnectExecute(NULL);
  //инициализация переменных:
  Bm = new Graphics::TBitmap;
  FCursor = 0;
  FCursorX = 0;    //обнуление координаты курсора
  SetDefColours(); //установка цветов по умолчанию
  FModified = 0;
  FMode = 0;
  FRef = 0;
  //чтение конфигурации:
  Lock = 1;
  ReadConfig();
  Lock = 0;
  //текущий режим:
  FGMode = MD_STOP;                   //запись графика остановлена
  Disconnect();
  Clear();
  ClearScale();
  Timer1->Interval = FSample;
  Timer1->Enabled = 1;                //разрешение таймера
}

//----------------------- Запрос закрытия формы: ----------------------------

void __fastcall TMainForm::FormCloseQuery(TObject *Sender, bool &CanClose)
{
	int Ans = IDNO;
  if(FModified)
   Ans = MessageDlg("Data modified. Save changes?", mtConfirmation,
                    TMsgDlgButtons() << mbYes << mbNo << mbCancel, 0);
  if(Ans == IDYES) acSaveasExecute(NULL);
  if(Ans == IDCANCEL) CanClose = 0;
}

//-------------------------- Закрытие формы: --------------------------------

void __fastcall TMainForm::FormClose(TObject *Sender, TCloseAction &Action)
{
  SaveConfig();
  Disconnect();
  delete Bm;
}

//------------------ Принятие файла по Drag-n-drop: -------------------------

void __fastcall TMainForm::WmDropFiles(TWMDropFiles &Message)
{
	HDROP drop_handle = (HDROP)Message.Drop;
	char fName[MAXPATH];
	DragQueryFile(drop_handle, 0, fName, MAXPATH);
	ReadData(fName);
	DragFinish(drop_handle);
}

//-------------------- Формирование заголовка окна: -------------------------

AnsiString __fastcall TMainForm::MakeCaption(void)
{
  DecimalSeparator = '.';
  AnsiString s = SOFTNAME;
  s = s + " " + FloatToStrF(VERSION, ffFixed, 3, 2);
  return(s);
}

//-------------------- Установка цветов по умолчанию: -----------------------

void __fastcall TMainForm::SetDefColours(void)
{
  Col_Bg = (TColor)16777215; //RGB(255,255,255);
  Col_Ax = (TColor)13948116; //RGB(172,172,172);
  Col_Tx = (TColor)4737096;  //RGB(0,0,0);
  Col_Cr = (TColor)0;        //RGB(0,0,0);
  Col_G1 = (TColor)32768;    //RGB(255,0,0);
  Col_G2 = (TColor)255;      //RGB(0,128,0);
  Col_G3 = (TColor)4227327;  //RGB(0,0,255);
  Col_G4 = (TColor)16711680; //RGB(255,92,92);
  Col_G5 = (TColor)4259584;  //RGB(0,255,64);
  Col_G6 = (TColor)12615935; //RGB(255,128,192);
}

//------------------------- Чтение INI-файла: -------------------------------

void __fastcall TMainForm::ReadConfig(void)
{
  TMemIniFile *ini;
  ini = new TMemIniFile(ChangeFileExt(Application->ExeName,".ini" ));
  Left = ini->ReadInteger("General","Left",Left);
  Top = ini->ReadInteger("General","Top",Top);
  Width = ini->ReadInteger("General","Width",Width);
  Height = ini->ReadInteger("General","Height",Height);
  WindowState = TWindowState(ini->ReadInteger("General", "WindowState", WindowState));
  FDataDir = ini->ReadString("General","DataDir",ExtractFilePath(ParamStr(0)));
  FPortNumber = ini->ReadInteger("General","Port",0);
  cbGr1->Checked = ini->ReadBool("General","ShowG1",1);
  cbGr2->Checked = ini->ReadBool("General","ShowG2",1);
  cbGr3->Checked = ini->ReadBool("General","ShowG3",0);
  cbGr4->Checked = ini->ReadBool("General","ShowG4",0);
  cbGr5->Checked = ini->ReadBool("General","ShowG5",0);
  cbGr6->Checked = ini->ReadBool("General","ShowG6",0);
  FAutoConnect = ini->ReadBool("Settings","AutoConnect",1);
  FAutoLoad = ini->ReadBool("Settings","AutoLoad",1);
  FSample = ini->ReadInteger("Settings","Sample",20);
  FAutoScroll = ini->ReadBool("Settings","AutoScroll",1);
  Col_Bg = (TColor)ini->ReadInteger("Colours","Background",Col_Bg);
  Col_Ax = (TColor)ini->ReadInteger("Colours","Axis",Col_Ax);
  Col_Tx = (TColor)ini->ReadInteger("Colours","Text",Col_Tx);
  Col_Cr = (TColor)ini->ReadInteger("Colours","Cursor",Col_Cr);
  Col_G1 = (TColor)ini->ReadInteger("Colours","Graph1",Col_G1);
  Col_G2 = (TColor)ini->ReadInteger("Colours","Graph2",Col_G2);
  Col_G3 = (TColor)ini->ReadInteger("Colours","Graph3",Col_G3);
  Col_G4 = (TColor)ini->ReadInteger("Colours","Graph4",Col_G4);
  Col_G5 = (TColor)ini->ReadInteger("Colours","Graph5",Col_G5);
  Col_G6 = (TColor)ini->ReadInteger("Colours","Graph6",Col_G6);
  feDia->Value = ini->ReadFloat("Params","Diameter",7.8);
  feTape->Value = ini->ReadFloat("Params","Thickness",35.0);
  feSlip->Value = ini->ReadFloat("Params","Slip",0.1);
  fePoles->Value = ini->ReadInteger("Params","Poles",174);
  delete ini;
}

//----------------------- Сохранение INI-файла: -----------------------------

void __fastcall TMainForm::SaveConfig(void)
{
  TMemIniFile *ini;
  ini = new TMemIniFile(ChangeFileExt(Application->ExeName,".ini" ));
  ini->WriteInteger("General", "WindowState", WindowState);
  if (WindowState != wsMaximized)
   { ini->WriteInteger("General","Left",Left);
     ini->WriteInteger("General","Top",Top);
     ini->WriteInteger("General","Width",Width);
     ini->WriteInteger("General","Height",Height);
   }
  ini->WriteString("General","DataDir",FDataDir);
  ini->WriteInteger("General","Port",FPortNumber);
  ini->WriteBool("General","ShowG1",cbGr1->Checked);
  ini->WriteBool("General","ShowG2",cbGr2->Checked);
  ini->WriteBool("General","ShowG3",cbGr3->Checked);
  ini->WriteBool("General","ShowG4",cbGr4->Checked);
  ini->WriteBool("General","ShowG5",cbGr5->Checked);
  ini->WriteBool("General","ShowG6",cbGr6->Checked);
  ini->WriteBool("Settings","AutoConnect",FAutoConnect);
  ini->WriteBool("Settings","AutoRead",FAutoLoad);
  ini->WriteInteger("Settings","Sample",FSample);
  ini->WriteBool("Settings","AutoScroll",FAutoScroll);
  ini->WriteInteger("Colours","Background",Col_Bg);
  ini->WriteInteger("Colours","Axis",Col_Ax);
  ini->WriteInteger("Colours","Text",Col_Tx);
  ini->WriteInteger("Colours","Cursor",Col_Cr);
  ini->WriteInteger("Colours","Graph1",Col_G1);
  ini->WriteInteger("Colours","Graph2",Col_G2);
  ini->WriteInteger("Colours","Graph3",Col_G3);
  ini->WriteInteger("Colours","Graph4",Col_G4);
  ini->WriteInteger("Colours","Graph5",Col_G5);
  ini->WriteInteger("Colours","Graph6",Col_G6);
  ini->WriteFloat("Params","Diameter",feDia->Value);
  ini->WriteFloat("Params","Thickness",feTape->Value);
  ini->WriteFloat("Params","Slip",feSlip->Value);
  ini->WriteInteger("Params","Poles",fePoles->Value);
  try { ini->UpdateFile(); } catch (Exception &E)
   { MessageDlg(E.Message, mtError, TMsgDlgButtons() << mbOK, 0); }
  delete ini;
}

//------------------------ Чтение файла данных: -----------------------------

void __fastcall TMainForm::ReadData(AnsiString Name)
{
  //сохранение пути и имени файла:
  FDataDir = ExtractFilePath(Name);
  FFileName = ExtractFileName(Name);
  bool result = 1;
  TStringList *in = new TStringList();
  TStringList *line = new TStringList();
  TCursor Save_Cursor = Screen->Cursor;
  try
  {
    Screen->Cursor = crHourGlass;
    try
    {
      //чтение файла в StringList:
      in->LoadFromFile(Name);
      //если первая строка файла не содержит текста "Time",
      //то ошибка формата файла:
      if(!in->Strings[0].AnsiPos("Time"))
        throw EInOutError("Bad file format");
      acStopExecute(NULL); //остановка накопления массивов
      Clear(); //очистка массивов
      ClearScale(); //очистка шкал
      //восстановление набора графиков, сохраненных в файле:
      cbGr1->Checked = in->Strings[0].AnsiPos("G1");
      cbGr2->Checked = in->Strings[0].AnsiPos("G2");
      cbGr3->Checked = in->Strings[0].AnsiPos("G3");
      cbGr4->Checked = in->Strings[0].AnsiPos("G4");
      cbGr5->Checked = in->Strings[0].AnsiPos("G5");
      cbGr6->Checked = in->Strings[0].AnsiPos("G6");
      //подготовка к парсингу строк:
      line->Delimiter = '\t';
      for(int i = 1; i < in->Count; i++)
      {
        //построчная загрузка файла во второй StringList
        //в виде DelimitedText:
        line->DelimitedText = in->Strings[i];
        int j = 1; //первая колонка - время, пропускаем
        //FSample берем из первой колонки второй строки:
        if(i == 2) FSample = StrToInt(line->Strings[0]);
        //преобразуем данные колонок в int и сохраняем в массивах:
        Data1[FPointer] = StrToFloat(line->Strings[j++]);
        Data2[FPointer] = StrToFloat(line->Strings[j++]);
        Data3[FPointer] = StrToFloat(line->Strings[j++]);
        Data4[FPointer] = StrToFloat(line->Strings[j++]);
        Data5[FPointer] = StrToFloat(line->Strings[j++]);
        if(line->Count > j)
          Data6[FPointer] = StrToFloat(line->Strings[j]);
        FPointer++;
      }
    }
    catch (Exception &E)
    {
      MessageDlg("Bad file format.", mtError, TMsgDlgButtons() << mbOK, 0);
      result = 0;
    }
  }
  __finally
  {
    Screen->Cursor = Save_Cursor;
    delete in;
    delete line;
    //перерисовка графиков:
    RedrawAll();
  }
  if(result) //если файл был открыт успешно,
  {
    //обновление заголовка приложения:
    Caption = MakeCaption() + " - " + FFileName;
  }
}

//---------------------- Сохранение файла данных: --------------------------

void __fastcall TMainForm::SaveData(AnsiString Name)
{
  //сохранение пути и имени файла:
  FDataDir = ExtractFilePath(Name);
  FFileName = ExtractFileName(Name);
  //сохранение данных в файл:
  TStringList *out = new TStringList();
  TCursor Save_Cursor = Screen->Cursor;
  bool not_saved = 0;
  try
  {
    Screen->Cursor = crHourGlass;
    //формирование строки заголовка:
    AnsiString str = "Time";
    if(cbGr1->Checked) str = str + "\t" + "G1";
    if(cbGr2->Checked) str = str + "\t" + "G2";
    if(cbGr3->Checked) str = str + "\t" + "G3";
    if(cbGr4->Checked) str = str + "\t" + "G4";
    if(cbGr5->Checked) str = str + "\t" + "G5";
    if(cbGr6->Checked) str = str + "\t" + "G6";
    out->Add(str);
    //сохранение массивов:
    for(int i = 0; i < FPointer; i++)
    {
      str = IntToStr(i * FSample);
      str = str + "\t" + FloatToStr(Data1[i]);
      str = str + "\t" + FloatToStr(Data2[i]);
      str = str + "\t" + FloatToStr(Data3[i]);
      str = str + "\t" + FloatToStr(Data4[i]);
      str = str + "\t" + FloatToStr(Data5[i]);
      str = str + "\t" + FloatToStr(Data6[i]);
      out->Add(str);
    }
    try
    {
      out->SaveToFile(Name);
    }
    catch (Exception &E)
    {
      MessageDlg("Unable to save file.", mtError, TMsgDlgButtons() << mbOK, 0);
      not_saved = FModified;
    }
  }
  __finally
  {
    Screen->Cursor = Save_Cursor;
    delete out;
  }
  //обновление заголовка приложения:
  Caption = MakeCaption() + " - " + FFileName;
  FModified = not_saved;
}

//---------------------------------------------------------------------------
//------------------------------ Menus: -------------------------------------
//---------------------------------------------------------------------------

//----------------------------- Menu New: -----------------------------------

void __fastcall TMainForm::acNewExecute(TObject *Sender)
{
  Clear();
  RedrawAll();
  FFileName = "";
  Caption = MakeCaption();
  FModified = 0;
}

//----------------------------- Menu Open: ----------------------------------

void __fastcall TMainForm::acOpenExecute(TObject *Sender)
{
  //установка сепаратора, иначе после "засыпания" Windows
  //восстанавливается системный по умолчанию
  DecimalSeparator = '.';
  //заполнение полей диалога:
  OpenDialog->Title = "Open Data File";
  OpenDialog->InitialDir = FDataDir;
  OpenDialog->FileName = "";
  OpenDialog->Filter = "Data file (*.dat)|*.dat|All files (*.*)|*.*";
  OpenDialog->DefaultExt = "dat";
  //вызов диалога "Open...":
  if(!OpenDialog->Execute()) return;
  //перерисовка формы под окном диалога:
  Refresh();
  //чтение файла:
  ReadData(OpenDialog->FileName);
}

//--------------------------- Menu Save As: ---------------------------------

void __fastcall TMainForm::acSaveasExecute(TObject *Sender)
{
  //установка сепаратора, иначе после "засыпания" Windows
  //восстанавливается системный по умолчанию
  DecimalSeparator = '.';
  //заполнение полей диалога:
  SaveDialog->Title = "Save Data File";
  SaveDialog->InitialDir = FDataDir;
  SaveDialog->FileName = FFileName;
  SaveDialog->Filter = "Data file (*.dat)|*.dat|All files (*.*)|*.*";
  SaveDialog->DefaultExt = "dat";
  //вызов диалога "Save As...":
  if(!SaveDialog->Execute()) return;
  //перерисовка формы под окном диалога:
  Refresh();
  //сохранение файла:
  SaveData(SaveDialog->FileName);
}

//---------------------------- Menu Exit: -----------------------------------

void __fastcall TMainForm::acExitExecute(TObject *Sender)
{
  Close();
}

//----------------------------- Connect: ------------------------------------

void __fastcall TMainForm::acConnectExecute(TObject *Sender)
{
  if(!ConnectForm) ConnectForm = new TConnectForm(Application, &FPortNumber);
  if(ConnectForm->ShowModal() == mrOk)
  {
    Timer1->Enabled = 0;
    Disconnect();
    Connect();
    Timer1->Enabled = 1;
  }
}

void __fastcall TMainForm::Connect(void)
{
  try
  {
    WakePort->Open(FPortNumber);
    FPortName = WakePort->PortName;
    FDeviceName = WakePort->GetInfo(0);
    AnsiString name = DEVICE_NAME;
    FConnected = FDeviceName.SubString(1, name.Length()) == name;
    if(!FConnected) throw EInOutError("Unknown device");
    StatusBar->Panels->Items[0]->Text = " ON LINE: " +
      FDeviceName + " (" + FPortName + ") ";
    //автоматическое чтение параметров:
    if(FAutoLoad) acReadExecute(NULL);
  }
  catch(const EInOutError &e)
  {
    Disconnect();
  }
}

//---------------------------- Disconnect: ----------------------------------

void __fastcall TMainForm::acDisconnectExecute(TObject *Sender)
{
  Timer1->Enabled = 0;
  FPortNumber = 0;
  Disconnect();
}

void __fastcall TMainForm::Disconnect(void)
{
  WakePort->Close();
  FConnected = 0;
  FPortName = "";
  FDeviceName = "";
  if(FPortNumber) StatusBar->Panels->Items[0]->Text = " CONNECTING... ";
    else StatusBar->Panels->Items[0]->Text = " OFF LINE ";
}

//---------------------------- Read Params: ---------------------------------

void __fastcall TMainForm::acReadExecute(TObject *Sender)
{
  TCursor Save_Cursor = Screen->Cursor;
  try
  {
    Screen->Cursor = crHourGlass;
    if(FConnected)
    {
      GetParams();
    }
  }
  __finally { Screen->Cursor = Save_Cursor; }
}

//--------------------------- Write Params: ---------------------------------

void __fastcall TMainForm::acWriteExecute(TObject *Sender)
{
  TCursor Save_Cursor = Screen->Cursor;
  try
  {
    Screen->Cursor = crHourGlass;
    if(FConnected)
    {
      SetParams();
    }
  }
  __finally { Screen->Cursor = Save_Cursor; }
}

//---------------------------- Open Params: ---------------------------------

void __fastcall TMainForm::acParOpenExecute(TObject *Sender)
{
  //установка сепаратора, иначе после "засыпания" Windows
  //восстанавливается системный по умолчанию
  DecimalSeparator = '.';
  //заполнение полей диалога:
  OpenDialog->Title = "Open Params File";
  OpenDialog->InitialDir = FDataDir;
  OpenDialog->FileName = "";
  OpenDialog->Filter = "Params file (*.par)|*.par|All files (*.*)|*.*";
  OpenDialog->DefaultExt = "par";
  //вызов диалога "Open Params...":
  if(!OpenDialog->Execute()) return;
  //сохранение пути:
  FDataDir = ExtractFilePath(OpenDialog->FileName);
  //чтение файла параметров:
  TMemIniFile *ini;
  ini = new TMemIniFile(OpenDialog->FileName);
  Lock = 1;
  feP->Value = ini->ReadInteger("DPLL", "Kp", 100);
  feI->Value = ini->ReadInteger("DPLL", "Ki", 40);
  feD->Value = ini->ReadInteger("DPLL", "Kd", 45);
  Lock = 0;
  delete ini;
}

//--------------------------- Save Params: ----------------------------------

void __fastcall TMainForm::acParSaveExecute(TObject *Sender)
{
  //установка сепаратора, иначе после "засыпания" Windows
  //восстанавливается системный по умолчанию
  DecimalSeparator = '.';
  //заполнение полей диалога:
  SaveDialog->Title = "Save Params File";
  SaveDialog->InitialDir = FDataDir;
  SaveDialog->FileName = "Params1";
  SaveDialog->Filter = "Params file (*.par)|*.par|All files (*.*)|*.*";
  SaveDialog->DefaultExt = "par";
  //вызов диалога "Save Params...":
  if(!SaveDialog->Execute()) return;
  //сохранение пути:
  FDataDir = ExtractFilePath(SaveDialog->FileName);
  //сохранение файла параметров:
  TMemIniFile *ini;
  ini = new TMemIniFile(SaveDialog->FileName);
  ini->WriteInteger("DPLL", "Kp", feP->Value);
  ini->WriteInteger("DPLL", "Ki", feI->Value);
  ini->WriteInteger("DPLL", "Kd", feD->Value);
  try { ini->UpdateFile(); } catch (Exception &E)
   { MessageDlg(E.Message, mtError, TMsgDlgButtons() << mbOK, 0); }
  delete ini;
}

//---------------------------- Menu Start: ----------------------------------

void __fastcall TMainForm::acStartExecute(TObject *Sender)
{
  if(!acStart->Checked)
  {
    acStart->Checked = 1;
    acPause->Checked = 0;
    acStop->Checked = 0;
    if(FGMode == MD_STOP) acNewExecute(NULL);
    FGMode = MD_START;
    FModified = 1;
  }
  else
  {
    acStart->Checked = 0;
    acPause->Checked = 1;
    acStop->Checked = 0;
    FGMode = MD_PAUSE;
  }
}

//---------------------------- Menu Pause: ----------------------------------

void __fastcall TMainForm::acPauseExecute(TObject *Sender)
{
  if(acStop->Checked) return;
  if(!acPause->Checked)
  {
    acPause->Checked = 1;
    acStart->Checked = 0;
    acStop->Checked = 0;
    FGMode = MD_PAUSE;
  }
  else
  {
    acPause->Checked = 0;
    acStart->Checked = 1;
    acStop->Checked = 0;
    FGMode = MD_START;
  }
}

//----------------------------- Menu Stop: ----------------------------------

void __fastcall TMainForm::acStopExecute(TObject *Sender)
{
  acStop->Checked = 0;
  acStart->Checked = 0;
  acPause->Checked = 0;
  FGMode = MD_STOP;
}

//----------------------------- Menu Freeze: --------------------------------

void __fastcall TMainForm::acFreezeExecute(TObject *Sender)
{
  acFreeze->Checked = !acFreeze->Checked;
  if(!acFreeze->Checked) RedrawAll();
}

//---------------------------- Menu Test Data: ------------------------------

void __fastcall TMainForm::acTestExecute(TObject *Sender)
{
  double arg = 0;
  for(int i = 0; i < LOGN; i++)
  {
    double s = 1 + sin(arg);
    Data1[i] = 800 + 80 * s;
    Data2[i] = 600 + 70 * s;
    Data3[i] = 100 * s;
    Data4[i] = 200 * s;
    Data5[i] = 300 * s;
    Data6[i] = 400 * s;
    arg += 0.1;
  }
  FPointer = LOGN - 1;
  LogScrollBar->Position = 0;
  DrawLog(LogPaintBox->Canvas, 0, FPointer);
  RedrawAll();
}

//---------------------------- Menu Cursor: ---------------------------------

void __fastcall TMainForm::acCursorExecute(TObject *Sender)
{
  acCursor->Checked = !acCursor->Checked;
  FCursor = acCursor->Checked;
  DrawLogCur(LogPaintBox->Canvas, FCursor, FCursorX);
}

//----------------------------- Cut Left: -----------------------------------

void __fastcall TMainForm::acCutLExecute(TObject *Sender)
{
  if(FCursor)
  {
    int Xo = LogScrollBar->Position + FCursorX;
    if(Xo < FPointer)
    {
      for(int i = 0; i < FPointer - Xo; i++)
      {
        Data1[i] = Data1[i + Xo]; Data1[i + Xo] = 0;
        Data2[i] = Data2[i + Xo]; Data2[i + Xo] = 0;
        Data3[i] = Data3[i + Xo]; Data3[i + Xo] = 0;
        Data4[i] = Data4[i + Xo]; Data4[i + Xo] = 0;
        Data5[i] = Data5[i + Xo]; Data5[i + Xo] = 0;
        Data6[i] = Data6[i + Xo]; Data6[i + Xo] = 0;
      }
      FPointer = FPointer - Xo;
      FCursorX = 0;
      RedrawAll();
      LogScrollBar->Position = 0;
      FModified = 1;
    }
  }
}

//---------------------------- Cut Right: -----------------------------------

void __fastcall TMainForm::acCutRExecute(TObject *Sender)
{
  if(FCursor)
  {
    int Xo = LogScrollBar->Position + FCursorX;
    if(Xo < FPointer)
    {
      for(int i = Xo + 1; i < FPointer; i++)
      {
        Data1[i] = 0;
        Data2[i] = 0;
        Data3[i] = 0;
        Data4[i] = 0;
        Data5[i] = 0;
        Data6[i] = 0;
      }
      FPointer = Xo + 1;
      RedrawAll();
      FModified = 1;
    }
  }
}

//---------------------------- Menu Settings: -------------------------------

void __fastcall TMainForm::acSettingsExecute(TObject *Sender)
{
  if(!SettingsForm) SettingsForm = new TSettingsForm(Application);
  SettingsForm->ShowModal();
  Timer1->Interval = FSample;
  //автоматическая загрузка параметров:
  if(FAutoLoad) acReadExecute(NULL);
  RedrawAll();
}

//---------------------------- Menu Colours: --------------------------------

void __fastcall TMainForm::acColoursExecute(TObject *Sender)
{
  if(!ColoursForm) ColoursForm = new TColoursForm(Application);
  ColoursForm->ShowModal();
}

//---------------------------- Menu About: ----------------------------------

void __fastcall TMainForm::acAboutExecute(TObject *Sender)
{
  if(!AboutForm) AboutForm = new TAboutForm(Application);
  AboutForm->ShowModal();
}
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

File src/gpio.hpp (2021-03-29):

//----------------------------------------------------------------------------

//Реализация шаблонного класса TGpio

//----------------------------------------------------------------------------

#ifndef GPIO_HPP
#define	GPIO_HPP

//----------------------------- Классы портов: -------------------------------

#define DEFINE_PORT_CLASS(port_reg, ddr_reg, pin_reg, port_class_name) \
  class port_class_name\
    { public:\
	static uint8_t port()       { return(port_reg); }\
	static void port(uint8_t v) { port_reg = v; }\
	static uint8_t dir()        { return(ddr_reg); }\
	static void dir(uint8_t v)  { ddr_reg = v; }\
	static uint8_t pin()        { return(pin_reg); }\
	static void pin(uint8_t v)  { pin_reg = v; }\
    };

#ifdef PORTA0
DEFINE_PORT_CLASS(PORTA, DDRA, PINA, PORT_A)
#endif
#ifdef PORTB0
DEFINE_PORT_CLASS(PORTB, DDRB, PINB, PORT_B)
#endif
#ifdef PORTC0
DEFINE_PORT_CLASS(PORTC, DDRC, PINC, PORT_C)
#endif
#ifdef PORTD0
DEFINE_PORT_CLASS(PORTD, DDRD, PIND, PORT_D)
#endif
#ifdef PORTE0
DEFINE_PORT_CLASS(PORTE, DDRE, PINE, PORT_E)
#endif
#ifdef PORTF0
DEFINE_PORT_CLASS(PORTF, DDRF, PINF, PORT_F)
#endif
#ifdef PORTG0
DEFINE_PORT_CLASS(PORTG, DDRG, PING, PORT_G)
#endif
#ifdef PORTH0
DEFINE_PORT_CLASS(PORTH, DDRH, PINH, PORT_H)
#endif
#ifdef PORTL0
DEFINE_PORT_CLASS(PORTL, DDRL, PINL, PORT_L)
#endif

//----------------------------- Номера пинов: --------------------------------

enum PinNumber_t
{
  PIN_0,
  PIN_1,
  PIN_2,
  PIN_3,
  PIN_4,
  PIN_5,
  PIN_6,
  PIN_7
};

//------------------ Подтяжки/начальные состояния пинов: ---------------------

enum PinMode_t
{
  PIN_FLOAT = 0, //подтяжка выключена
  PIN_PULL  = 1, //подтяжка включена
  PIN_LOW   = 0, //начальное состояние LOW
  PIN_HIGH  = 1  //начальное состояние HIGH
};

//----------------------------------------------------------------------------
//------------------------ Шаблонный класс TGpio: ----------------------------
//----------------------------------------------------------------------------

template<class Port, PinNumber_t Pin>
class TGpio
{
public:
  TGpio() {};
  static void DirOut();
  static void DirOut(PinMode_t Mode);
  static void DirIn();
  static void DirIn(PinMode_t Mode);
  static void Pullup(PinMode_t Mode);
  static void Set();
  static void Clr();
  static bool Get();
  static bool GetLatch();
  void operator = (bool Value);
  operator bool();
};

//------------------------- Реализация методов: ------------------------------

template<class Port, PinNumber_t Pin>
inline void TGpio<Port, Pin>::DirOut()
{
  Port::dir(Port::dir() | (1 << Pin));
}

template<class Port, PinNumber_t Pin>
inline void TGpio<Port, Pin>::DirOut(PinMode_t Mode)
{
  (Mode)? Set() : Clr();
  Port::dir(Port::dir() | (1 << Pin));
}

template<class Port, PinNumber_t Pin>
inline void TGpio<Port, Pin>::DirIn()
{
  Port::dir(Port::dir() & ~(1 << Pin));
}

template<class Port, PinNumber_t Pin>
inline void TGpio<Port, Pin>::DirIn(PinMode_t Mode)
{
  (Mode)? Set() : Clr();
  Port::dir(Port::dir() & ~(1 << Pin));
}

template<class Port, PinNumber_t Pin>
inline void TGpio<Port, Pin>::Pullup(PinMode_t Mode)
{
  (Mode)? Set() : Clr();
}

template<class Port, PinNumber_t Pin>
inline void TGpio<Port, Pin>::Set()
{
  Port::port(Port::port() | (1 << Pin));
}

template<class Port, PinNumber_t Pin>
inline void TGpio<Port, Pin>::Clr()
{
  Port::port(Port::port() & ~(1 << Pin));
}

template<class Port, PinNumber_t Pin>
inline bool TGpio<Port, Pin>::Get()
{
  return(Port::pin() & (1 << Pin));
}

template<class Port, PinNumber_t Pin>
inline bool TGpio<Port, Pin>::GetLatch()
{
  return(Port::port() & (1 << Pin));
}

template<class Port, PinNumber_t Pin>
inline void TGpio<Port, Pin>::operator = (bool Value)
{
  Value? Set() : Clr();
}
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

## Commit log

2021-03-27 Добавлен проект контроллера ведущего двигателя магнитофона ТК-140 авторства leoniv
2021-03-28 Добавлен .gitignore
2021-03-28 Переработка для Arduino Mega 2560 и двигатель ДМ-5
    * Timer1 -> Timer4, PL0 (ICP4) - пин 49 - вход таходатчика
    * Timer2 PWM не изменился - пин 10 - ШИМ управления мотором
    Схема таходатчика как у leoniv, управляющее напряжение формируется
    через пассивный ФНЧ 220н/10кОм.
2021-03-29 Светодиод Arduino теперь показывает захват
2021-03-31 Добавлен проект программы-пульта
2021-06-14 Регуляция PID работает по скользящему усреднению 8 отсчетов фазы.
2021-06-16 Переработка с ардуины на первую печатную плату. Изменены PID по умолчанию.
2021-06-16 Добавлено торможение реле при смене скорости.
2021-06-19 Добавлены исходники макетной печатной платы и схемы
    [main.kicad_pcb, main.sch, motor_out_2.sch]
2021-06-21 Добавлено README
2021-06-21 Добавлена незаконченная чистовая схема rev1, симуляция фильтра ШИМ для ngspice.
    [analog.sch, main.kicad_pcb, main.sch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]
2021-06-21 Обновлен README
2021-06-21 Добавлены фото прототипа rev0
2021-06-21 README дополнен фото
2021-06-21 В схему добавлен забытый ZCD.
    [analog.sch, main.sch]
2021-11-02 Добавлена печатная плата rev1 (вероятно чистовая).
    + Обозначена и разведена схема ZCD;
    + Исключена схема аналогового перемножителя;
    * модуляция модулем синуса полностью цифровая;
    + LM324 использована полностью:
    * собран 2й PWM фильтр, подключенный к OC2A в отладочных целях;
    + Добавлен доп. светодиод, предназначенный для контроля за ZCD;
    + Исправлен разъем логических сигналов управления;
    + Всяки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
    [analog.sch, main.kicad_pcb, main.sch]
2021-11-02 Опечатка + немного описания ревизий.
2021-11-02 Опечатка.
2021-11-02 Документация.
